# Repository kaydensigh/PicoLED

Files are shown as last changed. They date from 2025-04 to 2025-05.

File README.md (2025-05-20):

<p align="middle">
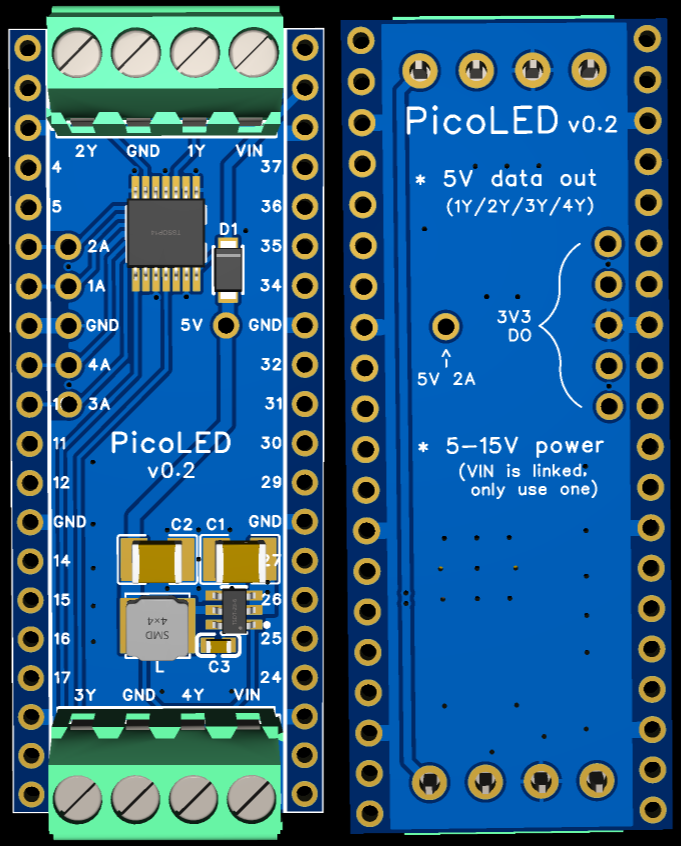
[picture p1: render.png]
  
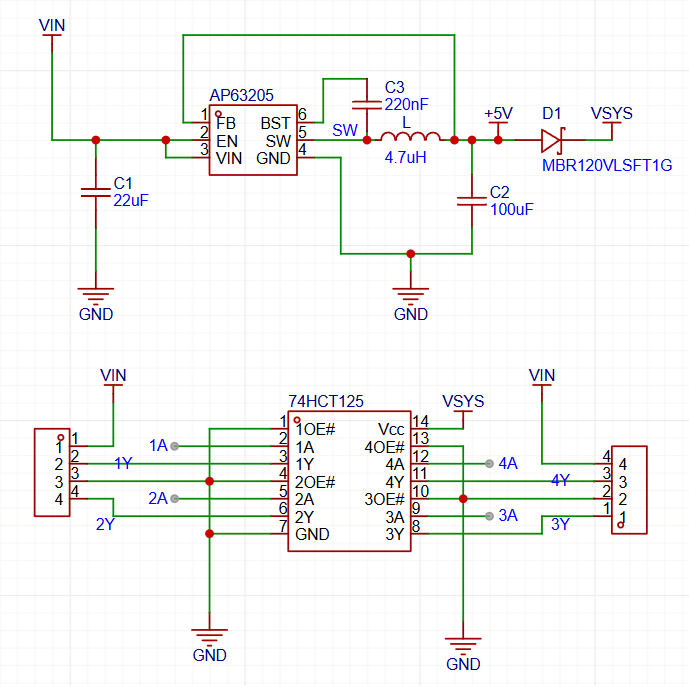
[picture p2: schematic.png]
   
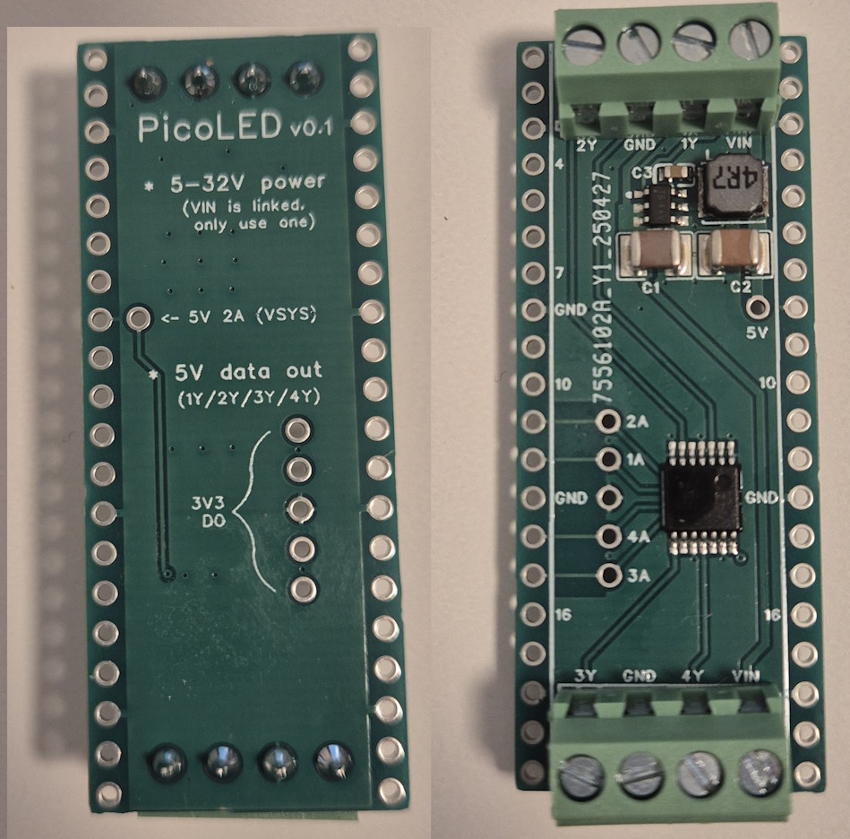
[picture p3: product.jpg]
   
</p>

# PicoLED

Raspberry Pi Pico HAT with:

- 5-32V power input (using AP63205)
- 4x 5V outputs (using 74HCT125)

Designed for controlling WS28xx LED strips and powering the Pico from the LED strip.

## PCB Design

Note: I'm not an expert so any advice is appreciated.

Done in EasyEDA, then exported to here so we can version control it.

### Pico GPIO

Using GP4-7 (pins 6-10) because they're a convenient position. The traces have a space where they can be cut if you don't want these. The 3v3 inputs to the level shifter are sized like and aligned with header through-holes, so they can be remapped.

### Screw terminals

The biggest one that can fit 4 terminals at each end of a Pico footprint.
Turned out to be 3.5mm, and there's space for GPIO headers on either side.

You may want smaller terminals if you want to mount the HAT under a Pico. I plan to put it on top of a W5500-EVB-Pico.

### Inductor

- Rated at 2A, with at least 2.7A I_sat.
- <100mR ESR.
- 4x4mm.

FB pin of AP63205 (reads 5V) avoids the inductor's eddy current area. (Not sure if really necessary).

### Capacitor ratings

The AP63205 datasheet gives suggested values for external components,
but it's a little unclear whether capacitances are effective or nominal.
(Ceramic capacitors lose capacitance with DC voltage, often by 80% over their rated voltage range).

I've selected (painstakingly, but with the help of https://yaqwsx.github.io/jlcparts/#/) capacitors where:
- DC bias characteristics are published by the manufacturer (by searching for the part number). Main manufacturers that provide this are: Samusung, Murata, Taiyo Yuden
- The effective capacitance at 24V/5V is within 20% of the value suggested in the datasheet.
- JLCPBC has stock.

As such, the capacitors used have much higher nominal capacitance than specified in the datasheet.
If the datasheet did already take this into account, using ~2x larger capacitance in decoupling capacitors probably doesn't hurt.

In the datasheet, the schematic indicates 2x22uF for the output capacitor, but both the discussion and the layout diagram use a single capacitor. I used a single one because smaller capacitors seemed to have much steeper capacitance loss with voltage.

## Pre-Manufacturing Checklist

In EasyEDA:

1. Rebuild copper regions for all layers.
1. Increment version number on silkscreen.
1. Take screenshots of schematic and 3D view.
1. Save project locally and export Gerber, BOM, PickAndPlace, Altium.
1. Git commit.

When ordering:

1. Select 1mm board thickness to match Pico.
1. Consider 2oz copper if making a large final run.

### Stock

I mostly picked parts that were available, but some things are less interchangeable.

In particular, AP63205 was in stock at LCSC but not JLCPCB. The options seemed to be:

- Pre-order it from JLCPCB's Parts Manager at 36 pieces minimum, ~0.24 USD each, plus ~26 USD once quoted (not sure if that's higher unit price or overheads), 24d lead time.
- Redesign with AP63200, but the datasheet recommends a much larger inductor, along with voltage-setting resistors.
- Redesign with a different device, but I couldn't find any that were comparably cheap, low-part-count, and could go down to a VCC of 5V (for 5V output).

I ended up just making a pre-order.

### Cost

PCB: 2 USD for 5 pieces (the usual JLCPCB special)

|Assembly | USD |
|---|---:|
| Setup fee | 8.00 |
| Stencil | 1.50 |
| Components | 6.79 |
| Extended components fee | 18.00 |
| SMT Assembly | 0.29 |
| Hand-soldering labor fee | 3.50 |
| Manual Assembly | 0.63 |
| Shipping (DHL) | 18.00 |
| | |
| Total | 56.71 |

So it looks like most of the cost is due to using many extended components, and the hand-soldering needed for the terminals.

This didn't include the preordered AP63205, which ended up costing 0.96 each. All up each piece cost 12.30.

IIUC, only the components, SMT assembly, and manual assembly fees scale with number of pieces, so extrapolating out to 30 pieces (my remaining AP63205 inventory), another order should cost 49 + 6 * 8.6 = 101, or 3.37 each.

Let me know if you're interested in splitting an order, or if you're ordering some yourself.

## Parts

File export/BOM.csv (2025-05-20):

No. | Quantity | Comment | Designator | Footprint | Value | Manufacturer Part | Manufacturer | Supplier Part | Supplier | JLCPCB Price
1 | 1 | 74HCT125T14-13 | 74HCT125 | TSSOP-14_L5.0-W4.4-P0.65-LS6.4-BL |  | 74HCT125T14-13 | DIODES(美台) | C842453 | LCSC | 0.1685
2 | 1 | AP63205WU-7 | AP63205 | TSOT-23-6_L2.9-W1.6-P0.95-LS2.8-BL |  | AP63205WU-7 | DIODES(美台) | C2071056 | LCSC | 0.372
3 | 1 | 22uF | C1 | C1210 | 22uF | GMK325BJ226MM-P | TAIYO YUDEN(太诱) | C778721 | LCSC | 0.2027
4 | 1 | 100uF | C2 | C1210 | 100uF | CL32A107MQVNNNE | SAMSUNG(三星) | C49066 | LCSC | 0.1292
5 | 1 | 220nF | C3 | C0603 | 220nF | CL10B224KB8NNNC | SAMSUNG(三星) | C64705 | LCSC | 0.0078
6 | 2 | DB125-3.5-4P-GN-S | CN1,CN2 | CONN-TH_DB125-3.5-4P-GN |  | DB125-3.5-4P-GN-S | DORABO(地博电气) | C2757925 | LCSC | 0.3497
7 | 1 | MBR120VLSFT1G | D1 | SOD-123F_L2.8-W1.8-LS3.7-RD |  | MBR120VLSFT1G | onsemi(安森美) | C223608 | LCSC | 0.1568
8 | 1 | 4.7uH | L | IND-SMD_L4.0-W4.0 | 4.7uH | CR4030-4R7M | ceaiya(柯爱亚) | C520319 | LCSC | 0.0414

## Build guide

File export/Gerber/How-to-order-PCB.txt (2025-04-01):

How to Order PCB

Please refer to:
https://prodocs.easyeda.com/en/pcb/order-order-pcb/index.html

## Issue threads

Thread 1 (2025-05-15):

Protect against high VIN inrush.

kaydensigh, 2025-05-15:
See https://github.com/VoronDesign/Voron-Tap/issues/42

This was solved using a 1R polyfuse on VIN, plus a Schottky diode for reverse polarity protection. But their design is always 24V, with a jumper to switch to direct 5V. If we want to automatically accept either voltage, we probably can't have these in the path with a 5V VIN.

kaydensigh, 2025-05-20:
https://www.analog.com/media/en/technical-documentation/application-notes/an88f.pdf, linked from that issue, has some good explanation and experimental results.

It sounds like adding an electrolytic capacitor would solve this, but I couldn't get a simulation to show this. We probably need a scope to check that this would work before shipping it.

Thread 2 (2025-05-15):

Reverse current protection.

kaydensigh, 2025-05-15:
When Pico VSYS is powered, but the PicoLED has no external power, something is goes wrong (it gets hot, but doesn't fry). We probably want a Schottky diode to prevent this. The voltage drop is probably fine since the Pico runs at 3v3 mostly, and the 74HCT125 tolerates down to 4.5V.

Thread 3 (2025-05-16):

Revisions to v0.1

kaydensigh, 2025-05-16:
- Thicker traces to GND pins.
- Silkscreen label for all pins.
- Move terminal labels away from terminals so they're not covered.
- Name and version on top.
